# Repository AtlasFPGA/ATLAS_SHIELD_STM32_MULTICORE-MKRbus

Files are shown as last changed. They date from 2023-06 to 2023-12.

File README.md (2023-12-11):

# ATLAS_SHIELD_STM32_MULTICORE-MKRbus

Primera versión del SHIELD MULTICORE STM32 MKRbus para I/O BOARD ATLAS, válido para todas las "I/O BOARD ATLAS" incluidas las "AKA NEPTUNE" se usan las hembras apiladas que normalmente se usan en los shield de arduino, para tener el multicore basado en STM32.

Group ATLAS in Telegram: https://t.me/INICIATIVAATLAS

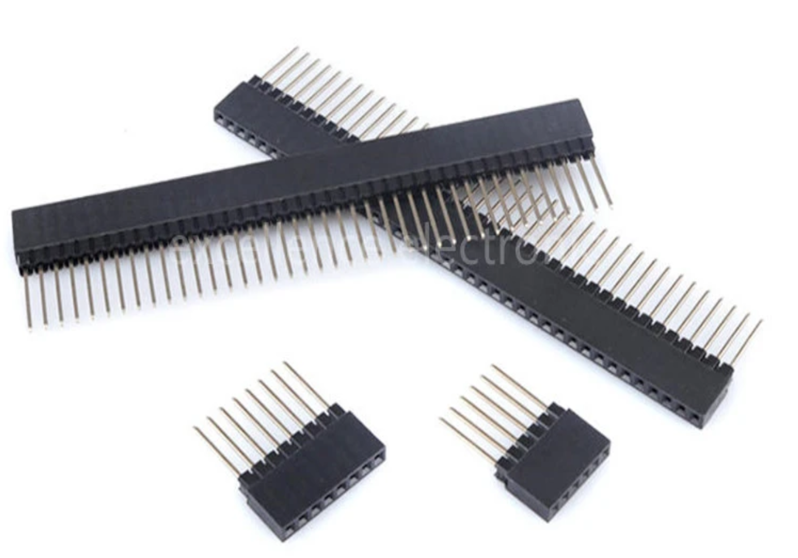
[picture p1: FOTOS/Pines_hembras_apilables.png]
Hembra apilable


Enlace cabezales hembra apilable:
https://es.aliexpress.com/item/4000059515638.html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

Las STM32 que se han usado son 2 modelos para el presente diseño SHIELD MULTICORE STM32:
Los modelos escogidos son el mismo que se usa en Muticore-II/UnAMIGA, pero en la versión de Victor Trucco, con una sóla SD en modo de acceso SPI 3V3, el modelo de tener microcontroladores o SBCs en el futuro es válido para futuros SHIELD MULTICORE que puedan aparecer con esta interconexión, al incorporar de esta forma la unión FPGA-SD-MICRO FPGA-SD-SBC, estamos en un puro derivado de MiST.

De hecho con el tiempo Victor trucco ha ido agregando más funcionalidad MiST a su versión con bluepill.

En este caso he colocado el mismo diseño que se ha usado en máquinas retro-fpga como,Multicore-II, UnAMIGA, Prototipos PEGASO & CENTAURO, Y las Retrofpga de más capacidad UnAMIGA-Reloaded y NePTUNO, puede que con eL añadido de VGA64 muchos cores de poca profundidad de color sean portables.

Como reservé 2 pines para un modo 4bit en SD, este se puede desarrollar con la BLACKPILL en la opción del chip más avanzado F411.
Hay por ahora tres modelos de BLACKPILL la BLACKPILL que posée SDIO de 1Bit, 4Bit u 8Bits -> SDIO es el STM32F411CEU6.

## Pineado bluepill

bluepill -> stm32f103c8t6

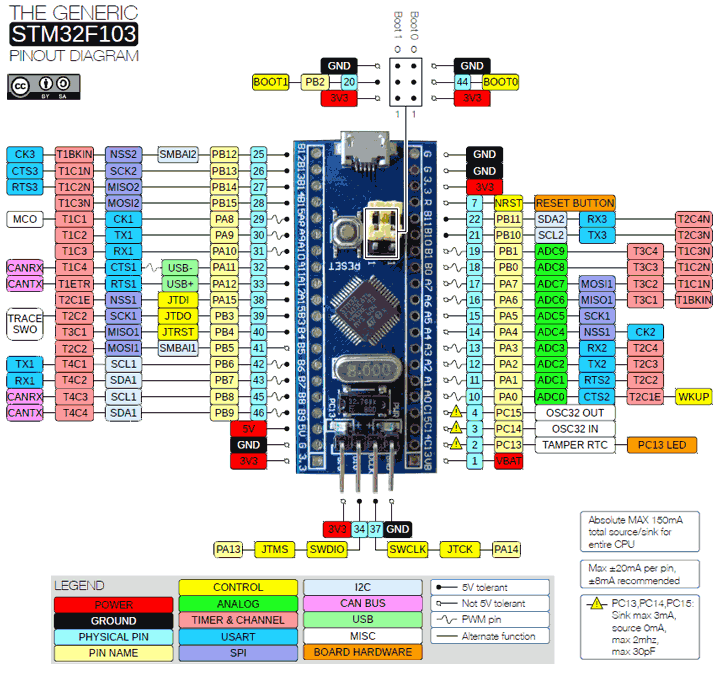
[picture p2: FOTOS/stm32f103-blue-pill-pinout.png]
pineado bluepill


## Pineado BLACKPILL

BLACKPILL -> STM32F411CEU6

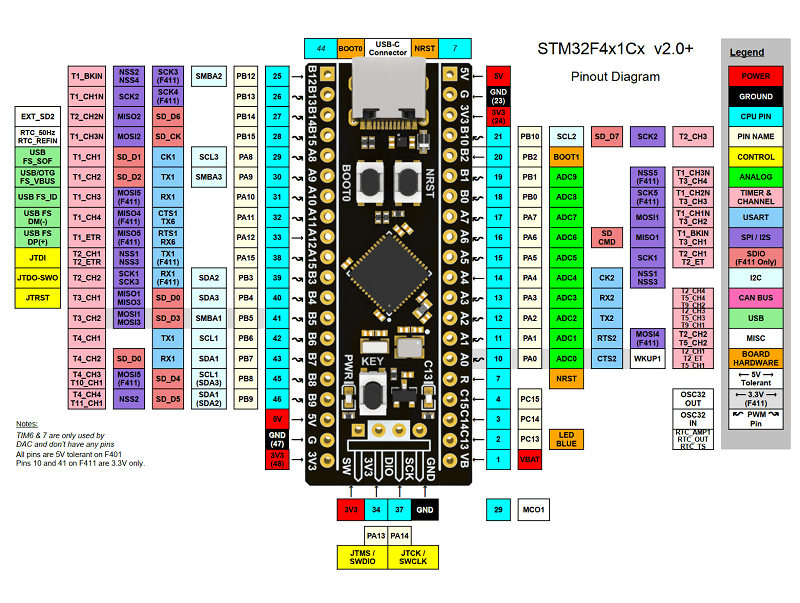
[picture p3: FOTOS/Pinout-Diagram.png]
PINEADO BLACKPILL


Nota: para posicionar correctamente los pines usamos mayúsculas para la BLACKPILL, y minúsculas para la bluepill.

## Dimensiones que compraten las STM32 usadas, a tener en cuenta de la bluepill y la BLACKPILL:
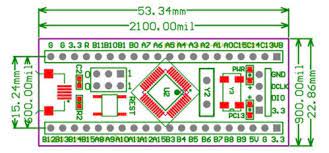
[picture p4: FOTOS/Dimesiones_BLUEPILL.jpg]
DIMENSIONES


Avance del esquema multicore STM32:
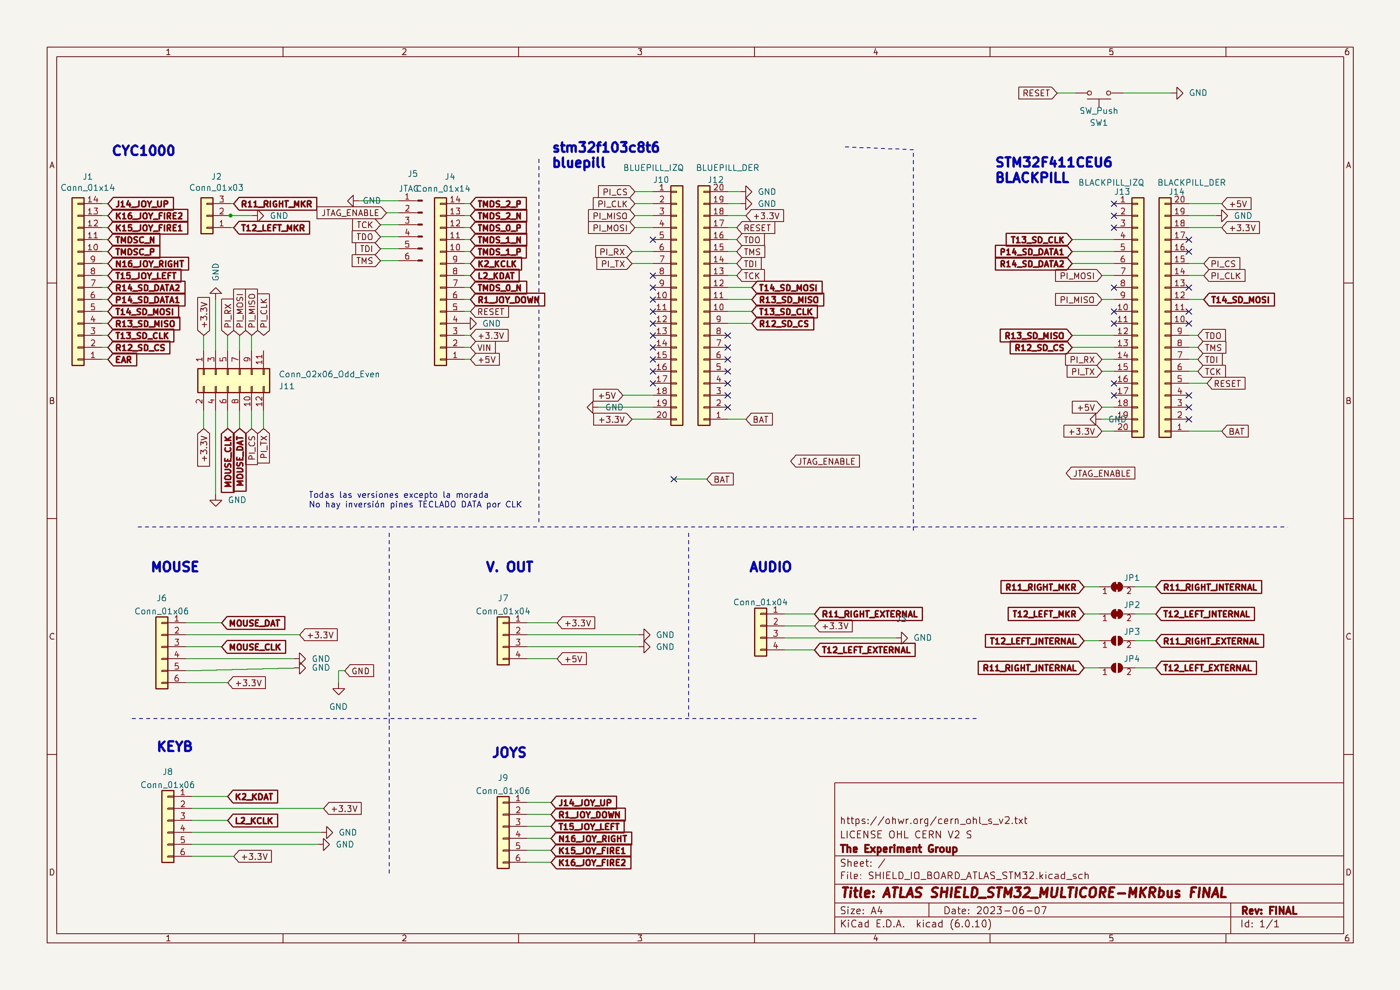
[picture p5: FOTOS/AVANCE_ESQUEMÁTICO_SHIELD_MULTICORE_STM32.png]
Diagrama multicore STM32


# NOTA: PI_TX y PI_RX pasarán as ser lineas de selección del modelo heredado por el Multicore II de Victor trucco.
# La colocación de los STM32, son excluyentes.

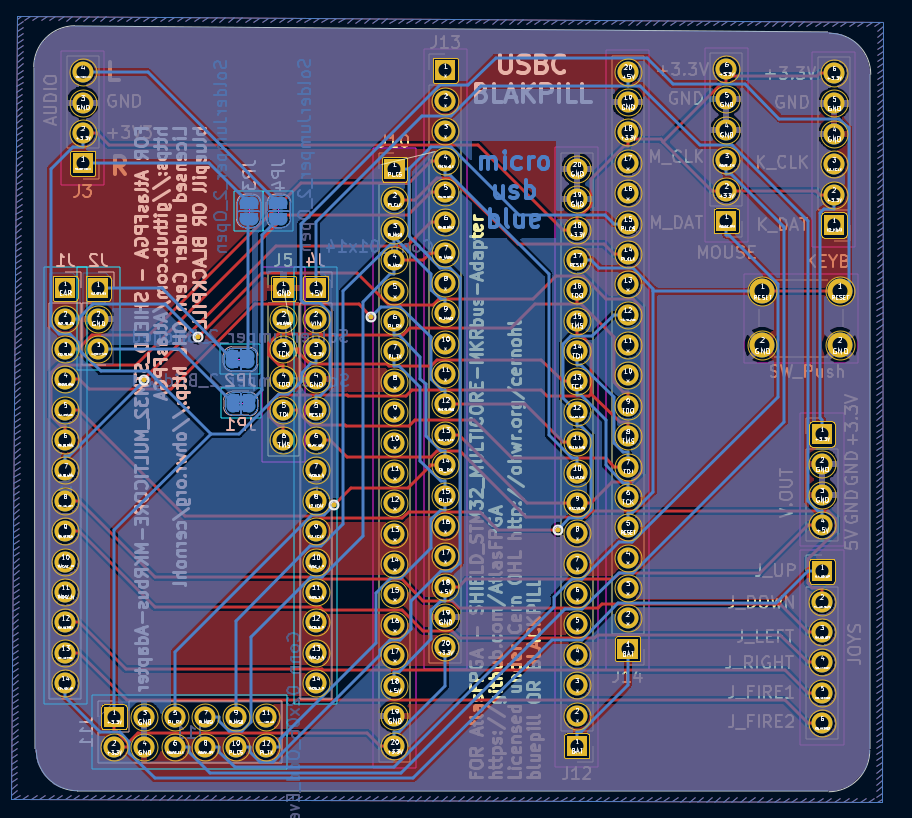
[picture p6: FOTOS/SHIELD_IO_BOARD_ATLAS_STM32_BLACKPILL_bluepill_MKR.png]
PRIMERA VERSIÓN SHIELD MULTICORE STM32


Al usar la elevación de las hembras apilables, el montaje "I/O BOARD ATLAS y LA SHIELD STM32" nos dá más capas, me queda la duda de si en el bus MKR+PMOD se puedieran cortar los pines asociados en la parte macho de las hembras apilables apoderándose de las señales Reservadas hasta la fecha, R14_SD_DATA2 y P14_SD_DATA1 así como el AUDIO Estéreo y T12_LEFT_MKR R11_RIGHT_MKR, agregando 4 señales a esta opción de Multicore con bluepill, estoy planteado en el futuro agregar esta opción de robar pines a la FPGA incorporando 4 señales a un nuevo diseño opcional, lo que permite conectar desde Dispositivos SPI, I2S, 2 canales I2C, TX RX con gestión de bflujo -> Acceso a internet.

Si se guardan los pines cortados iniciando el diseño con el bluepill y en el futuro se desarrollara una opción viable con SDIO 4Bit en BLACKPILL, no es muy dificil volver a soldarlos donde se realizó el corte, o directamente no usar ese tipo de hembras apilables en el conector de audio -> poner simples hembras, y hacer lo mismo en DATA1 y DATA2, y ya se veria como colocar pads normalmente abiertos o cerrados para que una misma placa permita obtener pines de fpga.

Aunque gestionando la compra de placas bien podía costearse una placa para bluepill + 4Señales, y BLACHPILL modelo F411.

Mi opción inicial es que se puedan manejar más componentes hardware, y unificar la placa sin agregar más que conectores cortar o soldar pistas en los pad indicados.

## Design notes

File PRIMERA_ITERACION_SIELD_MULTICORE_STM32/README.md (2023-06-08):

# Documentos del proyecto kicad asociado al SHIELD MULTICORE STM32
STM32 Multicore STM32 for plug a bluepill or BLACKPILL with CYC1000 in MKR bus for sxpand the use of Atlas resources

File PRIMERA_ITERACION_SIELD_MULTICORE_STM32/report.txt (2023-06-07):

Info: Se ha creado la carpeta de salida 'C:\Users\subcr\OneDrive\Escritorio\Atlas_ESP32_DEV_KIT_V1_001\RECOLOCADOR_ESP32_DEV_KIT_V1_VERSIONFINAL\gerbers'.
Plotted to 'C:\Users\subcr\OneDrive\Escritorio\Atlas_ESP32_DEV_KIT_V1_001\RECOLOCADOR_ESP32_DEV_KIT_V1_VERSIONFINAL\gerbers\RECOLOCADOR_ESP32_DEV_KIT_V1_VERSIONFINAL-F_Cu.gtl'.
Plotted to 'C:\Users\subcr\OneDrive\Escritorio\Atlas_ESP32_DEV_KIT_V1_001\RECOLOCADOR_ESP32_DEV_KIT_V1_VERSIONFINAL\gerbers\RECOLOCADOR_ESP32_DEV_KIT_V1_VERSIONFINAL-B_Cu.gbl'.
Plotted to 'C:\Users\subcr\OneDrive\Escritorio\Atlas_ESP32_DEV_KIT_V1_001\RECOLOCADOR_ESP32_DEV_KIT_V1_VERSIONFINAL\gerbers\RECOLOCADOR_ESP32_DEV_KIT_V1_VERSIONFINAL-F_Paste.gtp'.
Plotted to 'C:\Users\subcr\OneDrive\Escritorio\Atlas_ESP32_DEV_KIT_V1_001\RECOLOCADOR_ESP32_DEV_KIT_V1_VERSIONFINAL\gerbers\RECOLOCADOR_ESP32_DEV_KIT_V1_VERSIONFINAL-B_Paste.gbp'.
Plotted to 'C:\Users\subcr\OneDrive\Escritorio\Atlas_ESP32_DEV_KIT_V1_001\RECOLOCADOR_ESP32_DEV_KIT_V1_VERSIONFINAL\gerbers\RECOLOCADOR_ESP32_DEV_KIT_V1_VERSIONFINAL-F_Silkscreen.gto'.
Plotted to 'C:\Users\subcr\OneDrive\Escritorio\Atlas_ESP32_DEV_KIT_V1_001\RECOLOCADOR_ESP32_DEV_KIT_V1_VERSIONFINAL\gerbers\RECOLOCADOR_ESP32_DEV_KIT_V1_VERSIONFINAL-B_Silkscreen.gbo'.
Plotted to 'C:\Users\subcr\OneDrive\Escritorio\Atlas_ESP32_DEV_KIT_V1_001\RECOLOCADOR_ESP32_DEV_KIT_V1_VERSIONFINAL\gerbers\RECOLOCADOR_ESP32_DEV_KIT_V1_VERSIONFINAL-F_Mask.gts'.
Plotted to 'C:\Users\subcr\OneDrive\Escritorio\Atlas_ESP32_DEV_KIT_V1_001\RECOLOCADOR_ESP32_DEV_KIT_V1_VERSIONFINAL\gerbers\RECOLOCADOR_ESP32_DEV_KIT_V1_VERSIONFINAL-B_Mask.gbs'.
Plotted to 'C:\Users\subcr\OneDrive\Escritorio\Atlas_ESP32_DEV_KIT_V1_001\RECOLOCADOR_ESP32_DEV_KIT_V1_VERSIONFINAL\gerbers\RECOLOCADOR_ESP32_DEV_KIT_V1_VERSIONFINAL-Edge_Cuts.gm1'.
Info: Listo.

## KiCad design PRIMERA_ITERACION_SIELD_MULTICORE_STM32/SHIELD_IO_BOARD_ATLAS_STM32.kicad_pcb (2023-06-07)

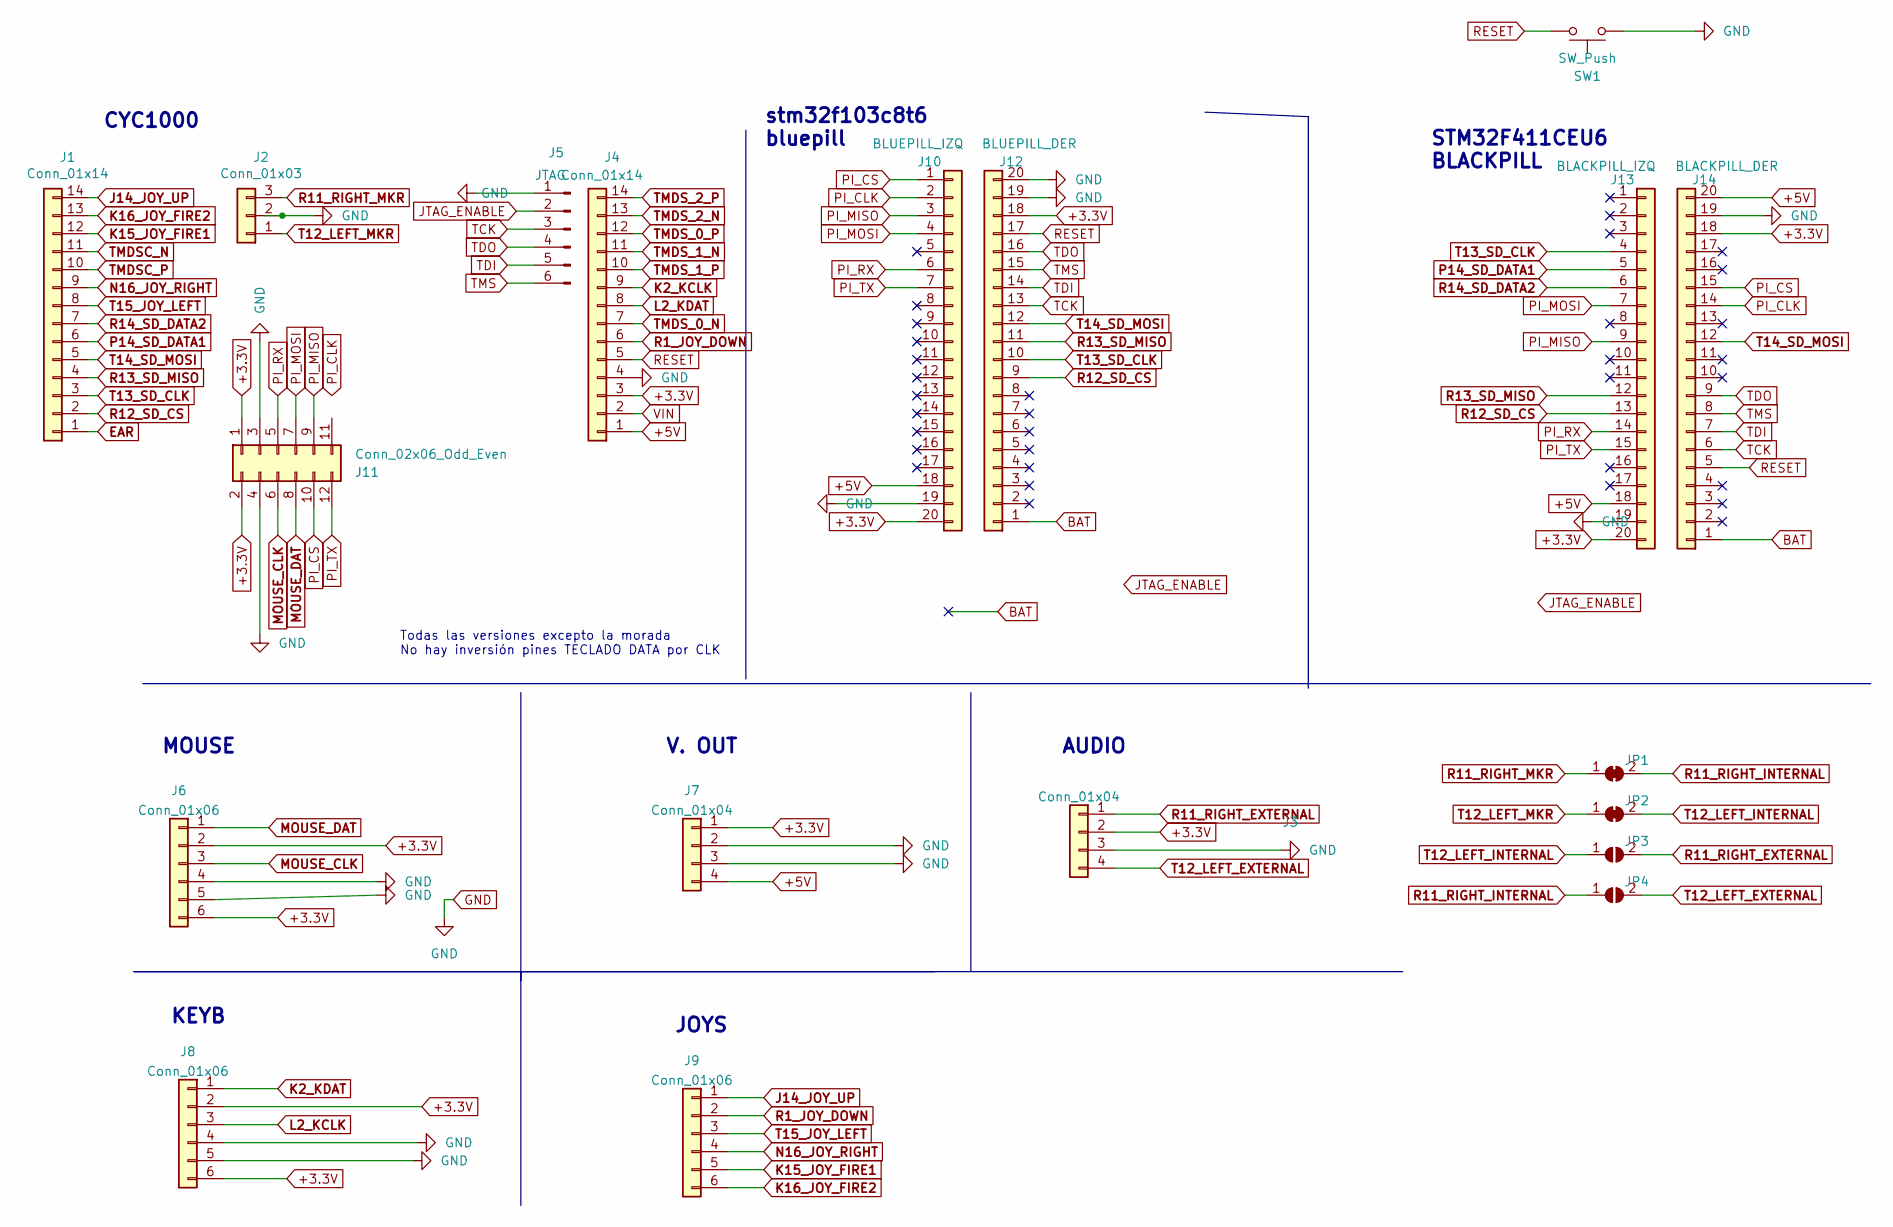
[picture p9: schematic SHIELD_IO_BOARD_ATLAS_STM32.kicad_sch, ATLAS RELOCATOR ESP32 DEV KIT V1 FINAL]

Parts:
J1, J4: Conn_01x14; PinHeader_1x14_P2.54mm_Vertical
J2: Conn_01x03; PinHeader_1x03_P2.54mm_Vertical
J3, J7: Conn_01x04; PinHeader_1x04_P2.54mm_Vertical
J5: JTAG; PinHeader_1x06_P2.54mm_Vertical
J6, J8, J9: Conn_01x06; PinHeader_1x06_P2.54mm_Vertical
J10: BLUEPILL_IZQ; PinHeader_1x20_P2.54mm_Vertical
J11: Conn_02x06_Odd_Even; PinHeader_2x06_P2.54mm_Vertical
J12: BLUEPILL_DER; PinHeader_1x20_P2.54mm_Vertical
J13: BLACKPILL_IZQ; PinHeader_1x20_P2.54mm_Vertical
J14: BLACKPILL_DER; PinHeader_1x20_P2.54mm_Vertical
JP1, JP2: SolderJumper_2_Bridged; SolderJumper-2_P1.3mm_Bridged2Bar_RoundedPad1.0x1.5mm
JP3, JP4: SolderJumper_2_Open; SolderJumper-2_P1.3mm_Open_RoundedPad1.0x1.5mm
SW1: SW_Push; SW_PUSH_6mm

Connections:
+3.3V: J3.2, J4.3, J6.2, J6.6, J7.1, J8.2, J8.6, J10.20, J11.1, J11.2, J12.18, J13.20, J14.18
+5V: J4.1, J7.4, J10.18, J13.18, J14.20
BAT: J12.1, J14.1
EAR: J1.1
GND: J2.2, J3.3, J4.4, J5.1, J6.4, J6.5, J7.2, J7.3, J8.4, J8.5, J10.19, J11.3, J11.4, J12.19, J12.20, J13.19, J14.19, SW1.2
J14_JOY_UP: J1.14, J9.1
JTAG_ENABLE: J5.2
K2_KCLK: J4.9
K2_KDAT: J8.1
K15_JOY_FIRE1: J1.12, J9.5
K16_JOY_FIRE2: J1.13, J9.6
L2_KCLK: J8.3
L2_KDAT: J4.8
MOUSE_CLK: J6.3, J11.6
MOUSE_DAT: J6.1, J11.8
N16_JOY_RIGHT: J1.9, J9.4
P14_SD_DATA1: J1.6, J13.5
PI_CLK: J10.2, J14.14
PI_CS: J10.1, J11.10, J14.15
PI_MISO: J10.3, J11.9, J13.9
PI_MOSI: J10.4, J11.7, J13.7
PI_RX: J10.6, J11.5, J13.14
PI_TX: J10.7, J11.12, J13.15
R1_JOY_DOWN: J4.6, J9.2
R11_RIGHT_EXTERNAL: J3.1, JP3.2 (B)
R11_RIGHT_INTERNAL: JP1.2 (B), JP4.1 (A)
R11_RIGHT_MKR: J2.3, JP1.1 (A)
R12_SD_CS: J1.2, J12.9, J13.13
R13_SD_MISO: J1.4, J12.11, J13.12
R14_SD_DATA2: J1.7, J13.6
RESET: J4.5, J12.17, J14.5, SW1.1
T12_LEFT_EXTERNAL: J3.4, JP4.2 (B)
T12_LEFT_INTERNAL: JP2.2 (B), JP3.1 (A)
T12_LEFT_MKR: J2.1, JP2.1 (A)
T13_SD_CLK: J1.3, J12.10, J13.4
T14_SD_MOSI: J1.5, J12.12, J14.12
T15_JOY_LEFT: J1.8, J9.3
TCK: J5.3, J12.13, J14.6
TDI: J5.5, J12.14, J14.7
TDO: J5.4, J12.16, J14.9
TMDSC_N: J1.11
TMDSC_P: J1.10
TMDS_0_N: J4.7
TMDS_0_P: J4.12
TMDS_1_N: J4.11
TMDS_1_P: J4.10
TMDS_2_N: J4.13
TMDS_2_P: J4.14
TMS: J5.6, J12.15, J14.8
VIN: J4.2

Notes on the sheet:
MOUSE
CYC1000
AUDIO
KEYB
JOYS
stm32f103c8t6 bluepill
Todas las versiones excepto la morada No hay inversión pines TECLADO DATA por CLK
STM32F411CEU6 BLACKPILL
V. OUT

Board: 2 copper layers, 19 parts (8 on the bottom side), 35 nets, no tracks yet.

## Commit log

2023-06-07 PRIMER README.md
    Multicore válido para BLACKPILL y BLUEPILL.
2023-06-07 Create Aclaración
    Inicio del proyecto en KICAD para el Multicore Shield STM32
2023-06-07 AÑADIDOS FICHEROS DE KICAD, MODELO UNA ÚNICA SD PARA ATLAS
    [SHIELD_IO_BOARD_ATLAS_STM32.dsn, SHIELD_IO_BOARD_ATLAS_STM32.kicad_pcb, SHIELD_IO_BOARD_ATLAS_STM32.kicad_sch]
2023-06-07 Imágenes de los STM32 usados, README.md
2023-06-07 Esquema común para desarrollo de un multicore STM32
    BLACKPILL -> SIO 4BIT
    bluepill -> SPI
2023-06-07 Agregada imagen del Diagrama multicore para bluepill y BLACKPILL README.md
2023-06-07 Añadir foto de Hembras apilables
2023-06-07 Añadir información sobre el cambio RX y TX Update README.md
    Las señales PI_RX y PI_TX pasarán a ser señales de selección, las mismas que usa Victor Trucco en su Multicore II.
2023-06-07 Agregada información sobre la placa SHIELD MULTICORE STM32 Update README.md
2023-06-07 Añadir infomación sobre hembras apilables
    Aclaración en texto a proceder en el futuro si se mezclan hembras con hembras apilables, si se desea usar un bluepill con 4 pines extra, o en el futuro un BLACKPILL F411 para desarrollar SDIO 4BIT.
2023-06-07 Aclarar futura opción PADs para agregar señales a bluepill-MiST
2023-06-07 Hablar de las señales capturadas en caso de usar BLUEPILL
2023-06-07 Mejorar redacción captura de pines al usar bluepill
2023-06-08 Agregar documentación al readme dell fichero alojado en el proyecto de KiCAD.

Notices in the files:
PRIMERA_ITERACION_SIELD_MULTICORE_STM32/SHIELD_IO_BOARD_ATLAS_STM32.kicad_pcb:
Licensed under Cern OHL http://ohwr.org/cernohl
